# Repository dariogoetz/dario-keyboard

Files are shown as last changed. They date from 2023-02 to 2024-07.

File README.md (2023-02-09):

# Ergonomic Split and Unibody 42-key Keyboards

Split and unibody variants of an ergonomic (column staggered) 42-key keyboard inspired by the [Cantor](https://github.com/diepala/cantor) keyboard and designed using [ergogen](https://github.com/ergogen/ergogen).

It uses a firmware based on [keyberon](https://github.com/TeXitoi/keyberon).

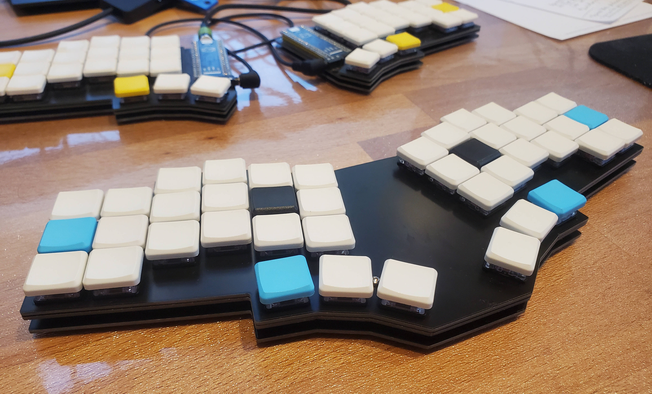
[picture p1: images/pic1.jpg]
Dario's keyboards


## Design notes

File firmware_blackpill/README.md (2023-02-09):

# Keyberon-based keyboard firmware for the Dario's keyboards

This is a keyboard firmware for Dario's keyboards based on [keyberon](https://github.com/TeXitoi/keyberon).

## Compiling

Install the rust toolchain

```shell
curl https://sh.rustup.rs -sSf | sh
rustup target add thumbv7em-none-eabihf
rustup component add llvm-tools-preview
cargo install cargo-binutils
cargo install flip-link
```
Moreover, you need the `dfu-util` binary which can normally be installed with your linux distribution's package manager.

Compile the firmware for the split keyboard with
```shell
cargo objcopy --release --bin split -- -O binary keyberon.bin
```
or for the unibody keyboard
```shell
cargo objcopy --release --bin unibody -- -O binary keyberon.bin
```

## Flashing using DFU

Put the developement board in DFU mode by holding reset and then pushing
and releasing boot. Then flash it:
```shell
dfu-util -a 0 --dfuse-address 0x08000000 -D keyberon.bin
```

## Development
Ensure that the debugging probe (e.g. STLink V2) has user access rights (see https://embedded-trainings.ferrous-systems.com/installation.html#linux-only-usb)

```shell
cargo install probe-run
cargo install probe-rs-cli
```

Running the program with log output:
```shell
DEFMT_LOG=info cargo run
```

## License

Licensed under either of

- Apache License, Version 2.0 ([LICENSE-APACHE](LICENSE-APACHE) or
  http://www.apache.org/licenses/LICENSE-2.0)

- MIT license ([LICENSE-MIT](LICENSE-MIT) or http://opensource.org/licenses/MIT)

at your option.

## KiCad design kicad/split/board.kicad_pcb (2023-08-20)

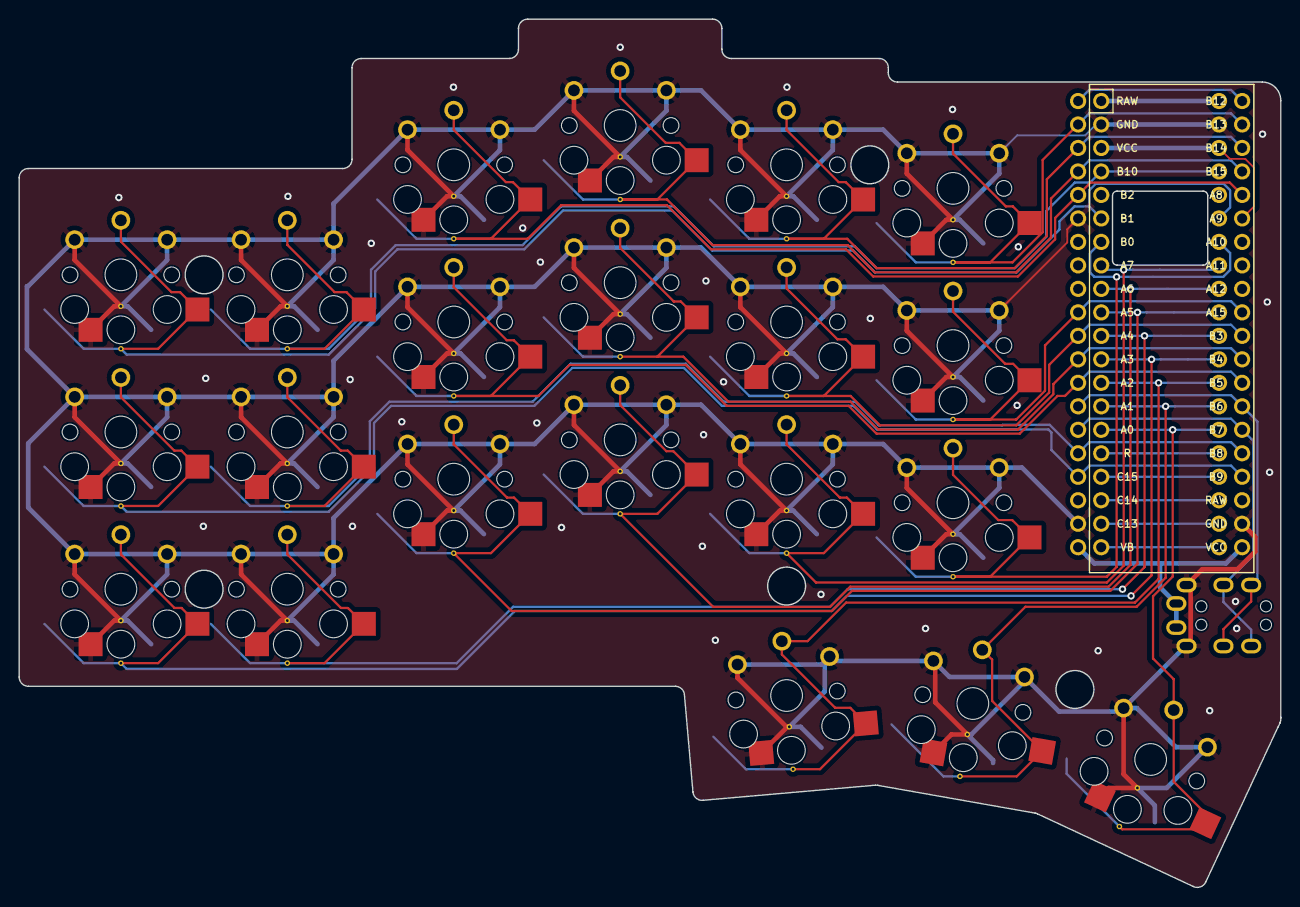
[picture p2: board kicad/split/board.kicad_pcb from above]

Board: 2 copper layers, 136.5 x 93.9 mm, 25 parts (0 on the bottom side), 36 nets.

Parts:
MCU1, MCU2: Blackpill
S1, S2, S3, S4, S5, S6, S7, S8, S9, S10, S11, S12, S13, S14, S15, S16, S17, S18, S19, S20, S21: PG1350
TRRS1, TRRS2: TRRS-PJ-320A-dual

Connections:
A0: MCU1.15, MCU2.15, S21.2
A1: MCU1.14, MCU2.14, S20.2
A2: MCU1.13, MCU2.13, S19.2
A3: MCU1.12, MCU2.12, S1.2
A4: MCU1.11, MCU2.11, S4.2
A5: MCU1.10, MCU2.10, S7.2
A6: MCU1.9, MCU2.9, S10.2
A7: MCU1.8, MCU2.8, S13.2
A8: MCU1.25, MCU2.25, S9.2
A10: MCU1.27, MCU2.27
A11: MCU1.28, MCU2.28
A12: MCU1.29, MCU2.29
A15: MCU1.30, MCU2.30, S17.2
B0: MCU1.7, MCU2.7, S16.2
B1: MCU1.6, MCU2.6, S3.2
B2: MCU1.5, MCU2.5
B3: MCU1.31, MCU2.31, S14.2
B4: MCU1.32, MCU2.32, S11.2
B5: MCU1.33, MCU2.33, S8.2
B6: MCU1.34, MCU2.34, TRRS1.3, TRRS2.4
B7: MCU1.35, MCU2.35, TRRS1.4, TRRS2.3
B8: MCU1.36, MCU2.36, S5.2
B9: MCU1.37, MCU2.37, S2.2
B10: MCU1.4, MCU2.4, S6.2
B12: MCU1.21, MCU2.21
B13: MCU1.22, MCU2.22, S18.2
B14: MCU1.23, MCU2.23, S15.2
B15: MCU1.24, MCU2.24, S12.2
C13: MCU1.19, MCU2.19
C14: MCU1.18, MCU2.18
C15: MCU1.17, MCU2.17
GND: MCU1.2, MCU1.39, MCU2.2, MCU2.26, MCU2.39, S1.1, S2.1, S3.1, S4.1, S5.1, S6.1, S7.1, S8.1, S9.1, S10.1, S11.1, S12.1, S13.1, S14.1, S15.1, S16.1, S17.1, S18.1, S19.1, S20.1, S21.1, TRRS1.2, TRRS2.2
R: MCU1.16, MCU2.16
RAW: MCU1.1, MCU1.38, MCU2.1, MCU2.38
VB: MCU1.20, MCU2.20
VCC: MCU1.3, MCU1.26, MCU1.40, MCU2.3, MCU2.40, TRRS1.1, TRRS2.1

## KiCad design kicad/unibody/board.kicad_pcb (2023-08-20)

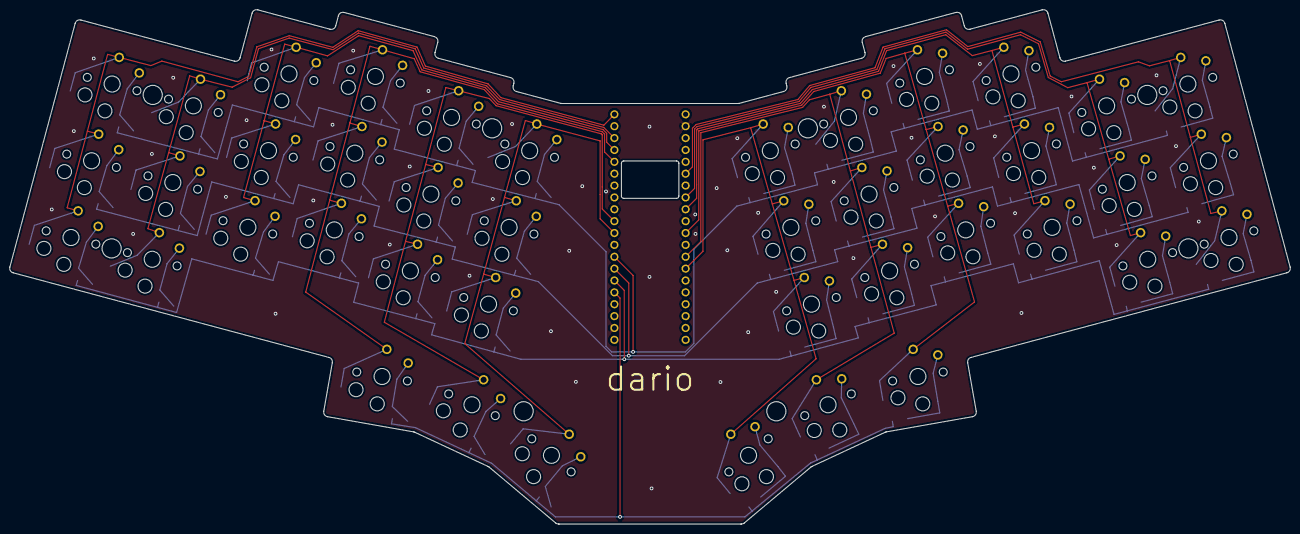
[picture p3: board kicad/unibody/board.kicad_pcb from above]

Board: 2 copper layers, 274.0 x 110.1 mm, 85 parts (0 on the bottom side), 61 nets.

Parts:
D1, D2, D3, D4, D5, D6, D7, D8, D9, D10, D11, D12, D13, D14, D15, D16, D17, D18, D19, D20, D21, D22, D23, D24, D25, D26, D27, D28, D29, D30, D31, D32, D33, D34, D35, D36, D37, D38, D39, D40, D41, D42: ComboDiode
MCU1: Blackpill
S1, S2, S3, S4, S5, S6, S7, S8, S9, S10, S11, S12, S13, S14, S15, S16, S17, S18, S19, S20, S21, S22, S23, S24, S25, S26, S27, S28, S29, S30, S31, S32, S33, S34, S35, S36, S37, S38, S39, S40, S41, S42: PG1350

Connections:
A1: MCU1.14, S37.2, S38.2, S39.2, S42.2
A2: MCU1.13, S34.2, S35.2, S36.2, S41.2
A4: MCU1.11, S31.2, S32.2, S33.2, S40.2
A6: MCU1.9, S28.2, S29.2, S30.2
A7: MCU1.8, S25.2, S26.2, S27.2
A8: MCU1.25, S10.2, S11.2, S12.2, S19.2
A15: MCU1.30, S13.2, S14.2, S15.2, S20.2
B1: MCU1.6, S22.2, S23.2, S24.2
B3: MCU1.31, S16.2, S17.2, S18.2, S21.2
B5: D3.1, D6.1, D9.1, D12.1, D15.1, D18.1, D24.1, D27.1, D30.1, D33.1, D36.1, D39.1, MCU1.33
B6: D2.1, D5.1, D8.1, D11.1, D14.1, D17.1, D23.1, D26.1, D29.1, D32.1, D35.1, D38.1, MCU1.34
B7: D1.1, D4.1, D7.1, D10.1, D13.1, D16.1, D22.1, D25.1, D28.1, D31.1, D34.1, D37.1, MCU1.35
B8: D19.1, D20.1, D21.1, D40.1, D41.1, D42.1, MCU1.36
B12: MCU1.21, S1.2, S2.2, S3.2
B14: MCU1.23, S4.2, S5.2, S6.2
B15: MCU1.24, S7.2, S8.2, S9.2
GND: MCU1.2, MCU1.39
RAW: MCU1.1, MCU1.38
VCC: MCU1.3, MCU1.40
center_thumb: D20.2, S20.1
index_bottom: D13.2, S13.1
index_home: D14.2, S14.1
index_top: D15.2, S15.1
inner_bottom: D16.2, S16.1
inner_home: D17.2, S17.1
inner_thumb: D19.2, S19.1
inner_top: D18.2, S18.1
middle_bottom: D10.2, S10.1
middle_home: D11.2, S11.1
middle_top: D12.2, S12.1
mirror_center_thumb: D41.2, S41.1
mirror_index_bottom: D34.2, S34.1
mirror_index_home: D35.2, S35.1
mirror_index_top: D36.2, S36.1
mirror_inner_bottom: D37.2, S37.1
mirror_inner_home: D38.2, S38.1
mirror_inner_thumb: D40.2, S40.1
mirror_inner_top: D39.2, S39.1
mirror_middle_bottom: D31.2, S31.1
mirror_middle_home: D32.2, S32.1
mirror_middle_top: D33.2, S33.1
mirror_outer_bottom: D22.2, S22.1
mirror_outer_home: D23.2, S23.1
mirror_outer_thumb: D42.2, S42.1
mirror_outer_top: D24.2, S24.1
mirror_pinky_bottom: D25.2, S25.1
mirror_pinky_home: D26.2, S26.1
mirror_pinky_top: D27.2, S27.1
mirror_ring_bottom: D28.2, S28.1
mirror_ring_home: D29.2, S29.1
mirror_ring_top: D30.2, S30.1
outer_bottom: D1.2, S1.1
outer_home: D2.2, S2.1
outer_thumb: D21.2, S21.1
outer_top: D3.2, S3.1
pinky_bottom: D4.2, S4.1
pinky_home: D5.2, S5.1
pinky_top: D6.2, S6.1
ring_bottom: D7.2, S7.1
ring_home: D8.2, S8.1
ring_top: D9.2, S9.1

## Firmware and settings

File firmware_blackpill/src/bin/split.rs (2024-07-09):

#![no_main]
#![no_std]

use core::sync::atomic::{AtomicUsize, Ordering};
use defmt_rtt as _; // global logger
use frunk::{HCons, HNil};
use hal::gpio::{EPin, Input};
use hal::otg_fs::{UsbBusType, USB};
use hal::prelude::*;
use hal::serial;
use keyberon::debounce::Debouncer;
use keyberon::layout::{CustomEvent, Event, Layout};
use keyberon::matrix::DirectPinMatrix;
use nb::block;
use stm32f4xx_hal as hal;
use synopsys_usb_otg::bus::UsbBus;
use systick_monotonic::*;
use usb_device::bus::UsbBusAllocator;
use usb_device::class::UsbClass as _;
use usb_device::device::UsbDeviceState;
use usb_device::prelude::*;
use usbd_human_interface_device::device::keyboard::{NKROBootKeyboard, NKROBootKeyboardConfig};
use usbd_human_interface_device::page::Keyboard;
use usbd_human_interface_device::usb_class::{UsbHidClass, UsbHidClassBuilder};

use panic_probe as _;

use dario_firmware_keyberon::layout;

/// USB VIP for a generic keyboard from
/// https://github.com/obdev/v-usb/blob/master/usbdrv/USB-IDs-for-free.txt
const VID: u16 = 0x16c0;

/// USB PID for a generic keyboard from
/// https://github.com/obdev/v-usb/blob/master/usbdrv/USB-IDs-for-free.txt
const PID: u16 = 0x27db;

// same panicking *behavior* as `panic-probe` but doesn't print a panic message
// this prevents the panic message being printed *twice* when `defmt::panic` is invoked
#[defmt::panic_handler]
fn panic() -> ! {
    cortex_m::asm::udf()
}

static COUNT: AtomicUsize = AtomicUsize::new(0);
defmt::timestamp!("{=usize}", {
    // NOTE(no-CAS) `timestamps` runs with interrupts disabled
    let n = COUNT.load(Ordering::Relaxed);
    COUNT.store(n + 1, Ordering::Relaxed);
    n
});

/// Terminates the application and makes `probe-run` exit with exit-code = 0
pub fn exit() -> ! {
    loop {
        cortex_m::asm::bkpt();
    }
}

type UsbClass =
    UsbHidClass<'static, UsbBus<USB>, HCons<NKROBootKeyboard<'static, UsbBus<USB>>, HNil>>;
type UsbDevice = usb_device::device::UsbDevice<'static, UsbBusType>;

#[rtic::app(device = stm32f4xx_hal::pac, dispatchers=[TIM1_CC])]
mod app {
    use super::*;

    #[monotonic(binds = SysTick, default = true)]
    type MyMono = Systick<100>; // 100 Hz / 10 ms granularity

    // shared resources (between tasks)
    #[shared]
    struct Shared {
        usb_dev: UsbDevice,
        usb_class: UsbClass,
        is_left_hand: bool,
        #[lock_free]
        layout: Layout<12, 4, 5, ()>,
    }

    // local resources (between tasks)
    #[local]
    struct Local {
        matrix: DirectPinMatrix<EPin<Input>, 6, 4>,
        debouncer: Debouncer<[[bool; 6]; 4]>,
        timer: hal::timer::counter::CounterHz<hal::pac::TIM2>,
        serial_tx: serial::Tx<hal::pac::USART1>,
        serial_rx: serial::Rx<hal::pac::USART1>,
        serial_buf: [u8; 4],
    }

    #[init]
    fn init(cx: init::Context) -> (Shared, Local, init::Monotonics) {
        // defmt::info!("init");
        // prepare static datastructures for USB
        static mut EP_MEMORY: [u32; 1024] = [0; 1024];
        static mut USB_BUS: Option<UsbBusAllocator<UsbBusType>> = None;

        // setup the monotonic timer
        let clocks = cx
            .device
            .RCC
            .constrain()
            .cfgr
            .use_hse(25.MHz())
            .sysclk(84.MHz())
            .require_pll48clk()
            .freeze();

        // Initialize the monotonic (SysTick rate in STM32F401 is 84MHz)
        let mono = Systick::new(cx.core.SYST, 84_000_000);

        // get GPIO pins
        let gpioa = cx.device.GPIOA.split();
        let gpiob = cx.device.GPIOB.split();

        // timer for processing keyboard events and sending a USB keyboard report
        let mut timer = cx.device.TIM2.counter_hz(&clocks);
        // or equivalently
        // let mut timer = hal::timer::Timer::new(cx.device.TIM2, &mut clocks).counter_hz();
        timer.start(1.kHz()).unwrap();
        timer.listen(hal::timer::Event::Update);

        // initialize USB
        let usb = USB {
            usb_global: cx.device.OTG_FS_GLOBAL,
            usb_device: cx.device.OTG_FS_DEVICE,
            usb_pwrclk: cx.device.OTG_FS_PWRCLK,
            pin_dm: gpioa.pa11.into_alternate().into(),
            pin_dp: gpioa.pa12.into_alternate().into(),
            hclk: clocks.hclk(),
        };

        unsafe {
            USB_BUS = Some(UsbBusType::new(usb, &mut EP_MEMORY));
        }

        let usb_bus = unsafe { USB_BUS.as_ref().unwrap() };
        let usb_class = UsbHidClassBuilder::new()
            .add_device(NKROBootKeyboardConfig::default())
            .build(usb_bus);

        let usb_dev = UsbDeviceBuilder::new(usb_bus, UsbVidPid(VID, PID))
            .manufacturer("Dario Götz")
            .product("Dario Götz's 42-key split keyboard")
            .serial_number(env!("CARGO_PKG_VERSION"))
            .build();

        // Setup USART communication with other half
        let (pb6, pb7) = (gpiob.pb6, gpiob.pb7);
        let serial_pins = cortex_m::interrupt::free(move |_cs| {
            (pb6.into_alternate::<7>(), pb7.into_alternate::<7>())
        });
        let mut serial = cx
            .device
            .USART1
            .serial(
                serial_pins,
                hal::serial::config::Config::default().baudrate(38_400.bps()),
                &clocks,
            )
            .unwrap();
        // or equivalently
        // let mut serial = serial::Serial::new(cx.device.USART1, pins, 38_400.bps(), &mut clocks);
        serial.listen(serial::Event::RxNotEmpty);
        let (serial_tx, serial_rx) = serial.split();

        let is_left_hand = gpioa.pa9.is_high();

        // define pin to matrix relation (prepare outside of interrupt::free closure
        // due to gpioa/gpiob move)
        let matrix_pins = [
            [
                Some(gpiob.pb1.into_pull_up_input().erase()),
                Some(gpiob.pb10.into_pull_up_input().erase()),
                Some(gpioa.pa8.into_pull_up_input().erase()),
                Some(gpiob.pb15.into_pull_up_input().erase()),
                Some(gpiob.pb14.into_pull_up_input().erase()),
                Some(gpiob.pb13.into_pull_up_input().erase()),
            ],
            [
                Some(gpiob.pb9.into_pull_up_input().erase()),
                Some(gpiob.pb8.into_pull_up_input().erase()),
                Some(gpiob.pb5.into_pull_up_input().erase()),
                Some(gpiob.pb4.into_pull_up_input().erase()),
                Some(gpiob.pb3.into_pull_up_input().erase()),
                Some(gpioa.pa15.into_pull_up_input().erase()),
            ],
            [
                Some(gpioa.pa3.into_pull_up_input().erase()),
                Some(gpioa.pa4.into_pull_up_input().erase()),
                Some(gpioa.pa5.into_pull_up_input().erase()),
                Some(gpioa.pa6.into_pull_up_input().erase()),
                Some(gpioa.pa7.into_pull_up_input().erase()),
                Some(gpiob.pb0.into_pull_up_input().erase()),
            ],
            [
                None,
                None,
                None,
                Some(gpioa.pa2.into_pull_up_input().erase()),
                Some(gpioa.pa1.into_pull_up_input().erase()),
                Some(gpioa.pa0.into_pull_up_input().erase()),
            ],
        ];
        let matrix = cortex_m::interrupt::free(move |_cs| DirectPinMatrix::new(matrix_pins));

        let mut layout = Layout::new(&layout::LAYERS);
        layout.add_tri_layer((1, 2), 3);

        (
            Shared {
                // Initialization of shared resources go here
                usb_dev,
                usb_class,
                is_left_hand,
                layout,
            },
            Local {
                // Initialization of local resources go here
                matrix: matrix.unwrap(),
                timer,
                debouncer: Debouncer::new([[false; 6]; 4], [[false; 6]; 4], 5),
                serial_tx,
                serial_rx,
                serial_buf: [0; 4],
            },
            init::Monotonics(mono),
        )
    }

    // Optional idle, can be removed if not needed.
    #[idle]
    fn idle(_: idle::Context) -> ! {
        loop {
            cortex_m::asm::wfi();
        }
    }

    /// Register a key press/release event with the layout (it will not be processed, yet)
    #[task(priority=1, capacity=8, shared=[layout])]
    fn register_keyboard_event(cx: register_keyboard_event::Context, event: Event) {
        // match event {
        //     Event::Press(i, j) => defmt::info!("Registering press {} {}", i, j),
        //     Event::Release(i, j) => defmt::info!("Registering release {} {}", i, j),
        // }
        cx.shared.layout.event(event)
    }

    /// Check all switches for their state, register corresponding events, and
    /// spawn generation of a USB keyboard report (including layout event processing)
    #[task(binds=TIM2, priority=1, local=[debouncer, matrix, timer, serial_tx], shared=[usb_dev, usb_class, layout, is_left_hand])]
    fn tick(mut cx: tick::Context) {
        let is_left_hand = cx.shared.is_left_hand.lock(|val| *val);

        // defmt::info!("Processing keyboard events");
        let is_host = cx.shared.usb_dev.lock(|d| d.state()) == UsbDeviceState::Configured;

        cx.local.timer.wait().ok();
        // or equivalently
        // cx.local.timer.clear_interrupt(hal::timer::Event::Update);

        // scan keyboard
        for event in cx
            .local
            .debouncer
            .events(cx.local.matrix.get().unwrap())
            .map(|e| transform_keypress_coordinates(e, is_left_hand))
        {
            // either register events or send to other half
            if is_host {
                cx.shared.layout.event(event)
            } else {
                for &b in &serialize(event) {
                    block!(cx.local.serial_tx.write(b)).unwrap();
                }
            }
            // match event {
            //     Event::Press(i, j) => defmt::info!("Pressed {} {}", i, j),
            //     Event::Release(i, j) => defmt::info!("Released {} {}", i, j),
            // }
        }

        let tick = cx.shared.layout.tick();
        if let CustomEvent::Release(()) = tick {
            unsafe { cortex_m::asm::bootload(0x1FFF0000 as _) }
        };

        // if this is the USB-side, send a USB keyboard report
        if is_host {
            while let Ok(()) = cx.shared.usb_class.lock(|k| {
                k.device()
                    .write_report(cx.shared.layout.keycodes().map(|k| Keyboard::from(k as u8)))
            }) {}
        }
    }

    /// Receive USART events from other keyboard half and register them
    #[task(binds = USART1, priority = 2, local = [serial_rx, serial_buf])]
    fn rx(cx: rx::Context) {
        // receive USART bytes and place into local buffer
        // if buffer is full (ends with '\n'), spawn event registration
        // received events (from other half) are mirrored (transformed)
        if let Ok(b) = cx.local.serial_rx.read() {
            cx.local.serial_buf.rotate_left(1);
            cx.local.serial_buf[3] = b;

            if cx.local.serial_buf[3] == b'\n' {
                if let Ok(event) = deserialize(&cx.local.serial_buf[..]) {
                    defmt::info!("Received message via USART");
                    register_keyboard_event::spawn(event).unwrap()
                }
            }
        }
    }

    fn deserialize(bytes: &[u8]) -> Result<Event, ()> {
        match *bytes {
            [b'P', i, j, b'\n'] => Ok(Event::Press(i, j)),
            [b'R', i, j, b'\n'] => Ok(Event::Release(i, j)),
            _ => Err(()),
        }
    }

    fn serialize(e: Event) -> [u8; 4] {
        match e {
            Event::Press(i, j) => [b'P', i, j, b'\n'],
            Event::Release(i, j) => [b'R', i, j, b'\n'],
        }
    }

    /// Transform key events from other keyboard half by mirroring coordinates
    fn transform_keypress_coordinates(e: Event, is_left_hand: bool) -> Event {
        // mirror coordinates for events for right half
        if is_left_hand {
            e
        } else {
            e.transform(|i, j| (i, 11 - j))
        }
    }

    // USB events
    #[task(binds = OTG_FS, priority = 3, shared = [usb_dev, usb_class])]
    fn usb_tx(cx: usb_tx::Context) {
        (cx.shared.usb_dev, cx.shared.usb_class).lock(|usb_dev, usb_class| {
            usb_poll(usb_dev, usb_class);
        });
    }

    #[task(binds = OTG_FS_WKUP, priority = 3, shared = [usb_dev, usb_class])]
    fn usb_rx(cx: usb_rx::Context) {
        (cx.shared.usb_dev, cx.shared.usb_class).lock(|usb_dev, usb_class| {
            usb_poll(usb_dev, usb_class);
        });
    }

    fn usb_poll(usb_dev: &mut UsbDevice, keyboard: &mut UsbClass) {
        if usb_dev.poll(&mut [keyboard]) {
            keyboard.poll();
        }
    }
}

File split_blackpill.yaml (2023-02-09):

units:
  cx: 18  # Choc X spacing
  cy: 17  # Choc Y spacing

points:
  key:
    padding: cy
    footprints:
      choc_hotswap:
        type: choc_optional
        nets:
          from: GND
          to: =pin
        params:
          reverse: true
          keycaps: true
          hotswap: true
          solder: true
        anchor:
          rotate: 180
      pin_via:
        type: via
        nets:
          net: =pin
        anchor:
          shift: [0, -0.5 cy + .5]
      gnd_via:
        type: via
        nets:
          net: GND
        anchor:
          shift: [0, -0.2 cy]

  zones:
    matrix:
      columns:
        outer:
          rows:
            top:
              pin: B1
            home:
              pin: B9
            bottom:
              pin: A3
        pinky:
          spread: cx
          rows:
            top:
              pin: B10
            home:
              pin: B8
            bottom:
              pin: A4
              bind: [2, 40, 2, 2]
        ring:
          stagger: 0.7cy
          spread: cx
          rows:
            top:
              pin: A8
            home:
              pin: B5
            bottom:
              pin: A5
        middle:
          stagger: 0.25cy
          spread: cx
          rows:
            top:
              pin: B15
            home:
              pin: B4
            bottom:
              pin: A6
              bind: [20, 7]
        index:
          stagger: -0.25cy
          spread: cx
          rows:
            top:
              pin: B14
            home:
              pin: B3
            bottom:
              pin: A7
        inner:
          spread: cx
          stagger: -0.15cy
          rows:
            top:
              pin: B13
            home:
              pin: A15
            bottom:
              pin: B0
              bind: [2, 10]
      rows:
        bottom:
          bind: 2
        home:
          bind: 2
        top:
          bind: [2, 3]

    thumb:
      anchor:
        ref: matrix_index_bottom
        shift: [0, -1.3cx]
        rotate: 5
      columns:
        inner:
          key:
            name: thumb_inner
            bind: [11, 4, 2, 2]
            pin: A2
        center:
          spread: 0.95 U
          rotate: -15
          origin: [-0.5cx, -0.5cy]
          key:
            name: thumb_center
            bind: [2, 2, 2, 3]
            pin: A1
        outer:
          spread: 0.95 U
          rotate: -15
          origin: [-0.5cx, -0.5cy]
          key:
            name: thumb_outer
            bind: [2, 2, 2, 12]
            pin: A0

outlines:
  exports:
    raw:
      - type: keys
        side: left
        size: [cx, cy]

    keywell:
      main:
        type: outline
        name: raw
        fillet: 1

    controller_area:
      main:
        type: rectangle
        anchor:
          ref:
            - matrix_inner_top
          shift: [0, -59.2]
        size: [35.45, 70.7]
        corner: 2

    reset_access:
      main:
        type: rectangle
        anchor:
          ref:
            - matrix_inner_top
          shift: [17.25, -8.3]
        size: [10.3, 8]
        corner: 0.5

    base_outline:
      main:
        type: outline
        name: keywell
      controller:
        type: outline
        name: controller_area
        operation: add
      reset_access:
        type: outline
        name: reset_access
        operation: subtract

    switches:
      - type: keys
        side: left
        bound: false
        size: [14, 14]

    screw_holes:
      top_left:
        type: circle
        anchor:
          - ref: matrix_pinky_top
            shift: [-0.5 cx, 0]
        radius: 1.05
      bottom_left:
        type: circle
        anchor:
          - ref: matrix_pinky_bottom
            shift: [-0.5 cx, 0]
        radius: 1.05
      top_right:
        type: circle
        anchor:
          - ref: matrix_index_top
            shift: [0.5 cx, 0]
        radius: 1.05
      palm:
        type: circle
        anchor:
          - ref: matrix_index_bottom
            shift: [0, -.68 cy]
        radius: 1.05
      thumb:
        type: circle
        anchor:
          - ref: thumb_outer
            shift: [-0.59 cx, 0.2cy]
        radius: 1.05

    mounting_holes:
      $extends: outlines.exports.screw_holes
      top_left:
        radius: 2.05
      bottom_left:
        radius: 2.05
      top_right:
        radius: 2.05
      palm:
        radius: 2.05
      thumb:
        radius: 2.05

    bottom_outline:
      main:
        type: outline
        name: base_outline
      screw_holes:
        type: outline
        name: screw_holes
        operation: subtract

    plate:
      main:
        type: outline
        name: keywell
      switches:
        type: outline
        name: switches
        operation: subtract
      mounting_holes:
        type: outline
        name: screw_holes
        operation: subtract
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

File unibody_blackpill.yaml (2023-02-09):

units:
  cx: 18  # Choc X spacing
  cy: 17  # Choc Y spacing
  distance: 51.5
  rotation: 15

points:
  key:
    padding: cy
    footprints:
      choc_hotswap:
        type: choc_optional
        nets:
          from: =colrow
          to: =column_net
        params:
          both_sides: false
          keycaps: true
          hotswap: true
          solder: true
          front: false
        anchor:
          rotate: 180
      # column_net_via:
      #   type: via
      #   nets:
      #     net: =column_net
      #   anchor:
      #     shift: [-0.1cx, -0.2 cy]
      # diode_via:
      #   type: via
      #   nets:
      #     net: =colrow
      #   anchor:
      #     shift: [0.1cx, -0.2 cy]
      diode:
        type: diode
        params:
          through_hole: false
          front: false
        nets:
          from: =colrow
          to: =row_net
        anchor:
          shift: [0.3 cx, -0.5 cy]
          rotate: 0

  zones:
    matrix:
      rotate: -rotation
      mirror: &mirror
        ref: matrix_inner_top
        distance: distance
      columns:
        outer:
          key:
            column_net: B12
            mirror:
              column_net: B1
            bind: 2
        pinky:
          spread: cx
          key:
            column_net: B14
            mirror:
              column_net: A7
            bind: 2
        ring:
          stagger: 0.7cy
          spread: cx
          key:
            column_net: B15
            mirror:
              column_net: A6
        middle:
          stagger: 0.25cy
          spread: cx
          key:
            column_net: A8
            mirror:
              column_net: A4
            bind: 2
        index:
          stagger: -0.25cy
          spread: cx
          key:
            column_net: A15
            mirror:
              column_net: A2
            bind: 2
        inner:
          spread: cx
          stagger: -0.15cy
          key:
            column_net: B3
            mirror:
              column_net: A1
            bind: 2
      rows:
        bottom:
          bind: [2, 40, 2, 2]
          row_net: B7
        home:
          bind: 2
          row_net: B6
        top:
          bind: [2, 3]
          row_net: B5

    thumb:
      mirror: *mirror
      anchor:
        ref: matrix_index_bottom
        shift: [0, -1.3cx]
        rotate: 5
      columns:
        inner:
          key:
            name: thumb_inner
            bind: [11, 4, 2, 2]
            column_net: A8
            mirror:
              column_net: A4
        center:
          spread: 0.95 U
          rotate: -15
          origin: [-0.5cx, -0.5cy]
          key:
            name: thumb_center
            bind: [3, 2, 2, 3]
            column_net: A15
            mirror:
              column_net: A2
        outer:
          spread: 0.95 U
          rotate: -15
          origin: [-0.5cx, -0.5cy]
          key:
            name: thumb_outer
            bind: [2, 2, 2, 12]
            column_net: B3
            mirror:
              column_net: A1
      rows:
        thumb:
          row_net: B8

outlines:
  glue:
    glue:
      top:
        left:
          ref: matrix_inner_top
          shift: [0, cx/2 + 2.5]
        right:
          ref: mirror_matrix_inner_top
          shift: [0, cx/2 + 2.5]
      bottom:
        left:
          ref: matrix_inner_bottom
          shift: [0, -cx]
        right:
          ref: mirror_matrix_inner_bottom
          shift: [0, -cx]
  exports:
    raw:
      - type: keys
        side: both
        size: [cx, cy]

    keywell:
      main:
        type: outline
        name: raw
        fillet: 1

    controller_area:
      main:
        type: rectangle
        anchor:
          ref:
            - matrix_inner_top
            - mirror_matrix_inner_top
          rotate: 0
          shift: [-cx - 1.5, -4.5cx + 1.1]
        size: [2cx + 3, 5cx]

    reset_access:
      main:
        type: rectangle
        anchor:
          ref:
            - matrix_inner_top
            - mirror_matrix_inner_top
          shift: [-6.12, -10.2]
        size: [12.3, 8]
        corner: 0.5

    mcu_access:
      main:
        type: rectangle
        anchor:
          ref:
            - matrix_inner_top
            - mirror_matrix_inner_top
          shift: [-11.0, -44.5]
        size: [22.0, 60]
        corner: 0.5

    base_outline:
      main:
        type: outline
        name: keywell
      controller:
        type: outline
        name: controller_area
        operation: add

    base_outline_reset_access:
      base_outline:
        type: outline
        name: base_outline
      reset_access:
        type: outline
        name: reset_access
        operation: subtract

    base_outline_mcu_access:
      base_outline:
        type: outline
        name: base_outline
      mcu_access:
        type: outline
        name: mcu_access
        operation: subtract

    switches:
      - type: keys
        side: both
        bound: false
        size: [14, 14]
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

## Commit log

2023-08-20 add: routed pcbs
    [board.kicad_pcb, bottom_plate.kicad_pcb, top_plate.kicad_pcb]
2023-12-01 mod: update stm32 package hal
